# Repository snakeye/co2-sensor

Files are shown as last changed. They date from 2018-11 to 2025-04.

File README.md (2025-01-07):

# Carbon Dioxide Sensor MH-Z19b - ESP8266 Prototype

This project utilizes the MH-Z19b carbon dioxide sensor module, which provides a simple and cost-effective way to measure CO2 concentration via UART interface. The sensor measures concentrations in the range of 0-5000ppm, making it suitable for various environmental monitoring applications.

The device is built using the ESP12e module and features an RGB LED to indicate CO2 concentration levels.

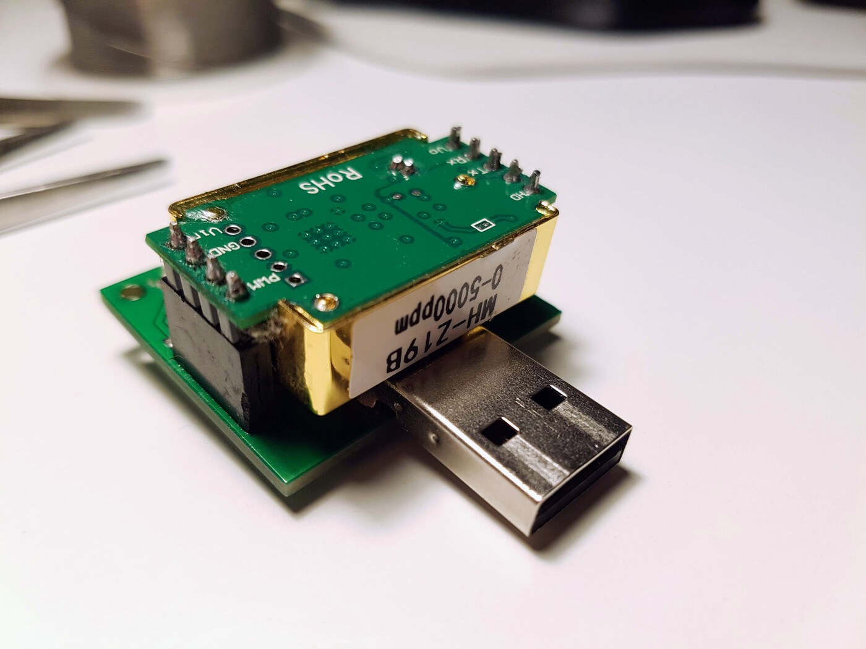
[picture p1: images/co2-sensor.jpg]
CO2 Sensor


## Features

- **CO2 concentration measurement** from 400ppm to 5000ppm using the MH-Z19b sensor.
- **RGB LED indication** with different light modes based on CO2 levels.
  
### LED Modes:

- **Steady Green Light**: CO2 concentration in the range of 400-1000ppm (normal levels).
- **Breathing Light**: Color changes from green to orange as CO2 levels increase from 1000 to 1500ppm.
- **Fast Breathing Light**: Color changes from orange to red as CO2 levels increase from 1500 to 2000ppm.
- **Fast Blinking Red Light**: CO2 concentration exceeds 2000ppm (dangerous levels).
- **Steady Blue Light**: Indicates that an OTA (Over-the-Air) update is in progress.

## Firmware

The firmware for the device is written using **PlatformIO** and the **Arduino** platform. The software controls the sensor, processes the data, and adjusts the LED indications based on the CO2 concentration.

## License

This project is licensed under the MIT License - see the [LICENSE](LICENSE) file for details.

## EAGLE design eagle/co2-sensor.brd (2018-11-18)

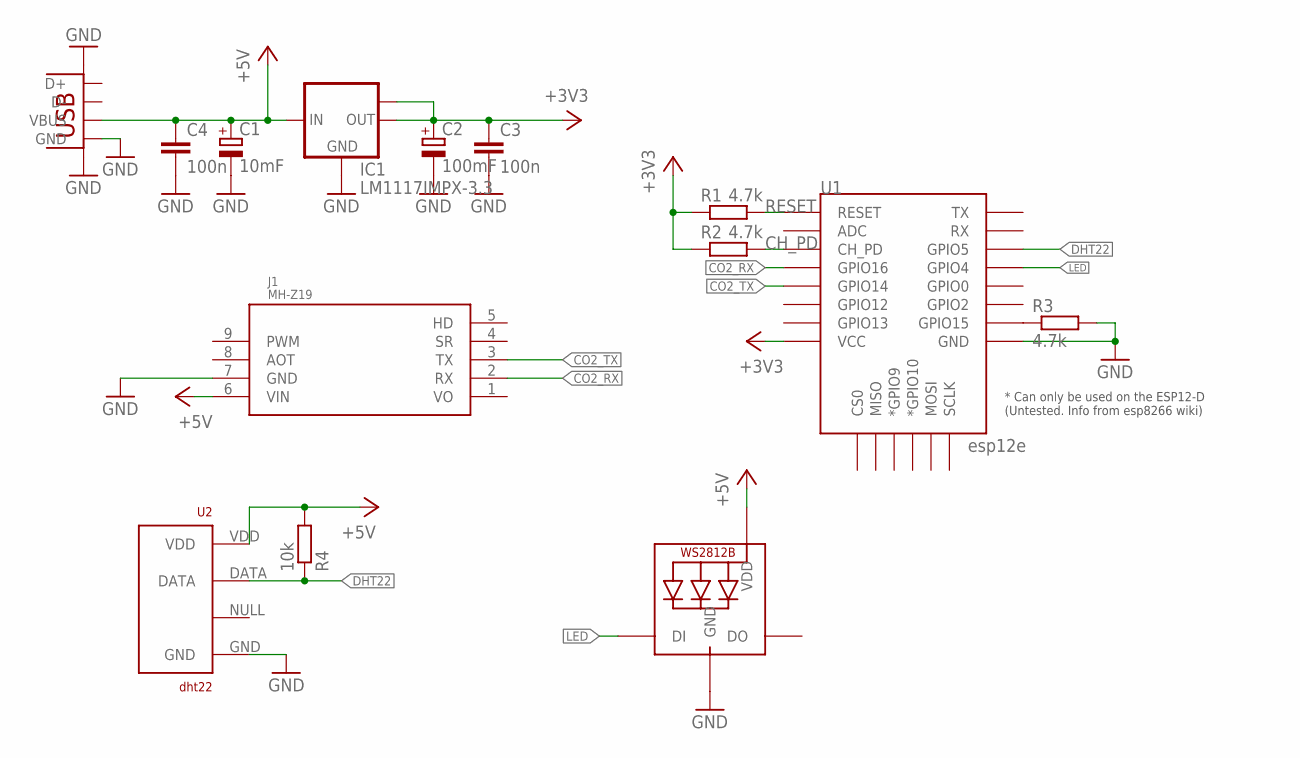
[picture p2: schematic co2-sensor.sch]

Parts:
C1: 10mF; CT3216
C2: 100mF; CT3216
C3, C4: 100n; C0805
IC1: LM1117IMPX-3.3; SOT223
J1: MH-Z19; MH-Z19-REV
LED1: WS2812B_5050N; WS2812B-NARROW
R1, R2, R3: 4.7k; M0805
R4: 10k; M0805
U1: esp12e; ESP12E-SMD
U2: dht22; AM2302
U$1: USB-A; USB-A-SMT

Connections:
+3V3: C2.+, C3.1, IC1.2 (OUT), IC1.TAB (OUT1), R1.1, R2.1, U1.VCC
+5V: C1.+, C4.1, IC1.3 (IN), J1.6 (VIN), LED1.1-VDD (VDD), R4.2, U2.VDD, U$1.P$6 (VBUS)
CH_PD: R2.2, U1.CH_PD
CO2_RX: J1.2 (RX), U1.GPIO16
CO2_TX: J1.3 (TX), U1.GPIO14
DHT22: R4.1, U1.GPIO5, U2.DATA
GND: C1.-, C2.-, C3.2, C4.2, IC1.1 (GND), J1.7 (GND), LED1.3-GND (GND), R3.2, U1.GND, U2.GND, U$1.P$1 (GND), U$1.P$2 (GND), U$1.P$3 (GND)
LED: LED1.4-DIN (DI), U1.GPIO4
unnamed: R3.1, U1.GPIO15
RESET: R1.2, U1.RESET
VO: J1.1 (VO)

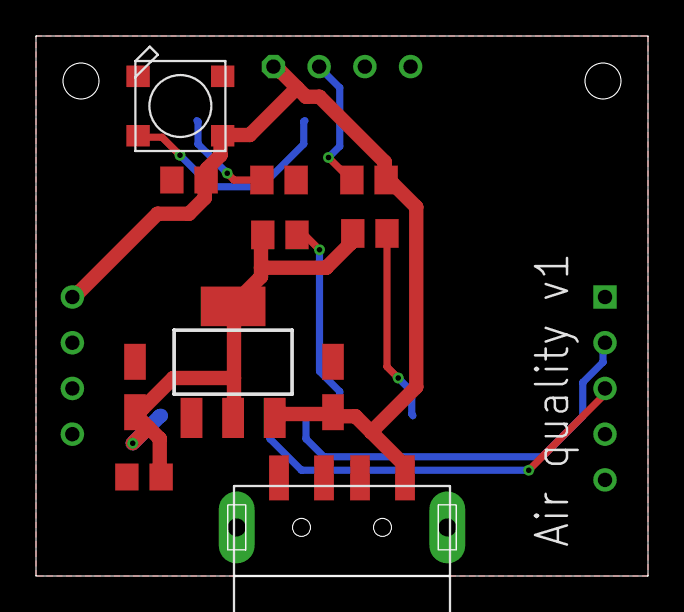
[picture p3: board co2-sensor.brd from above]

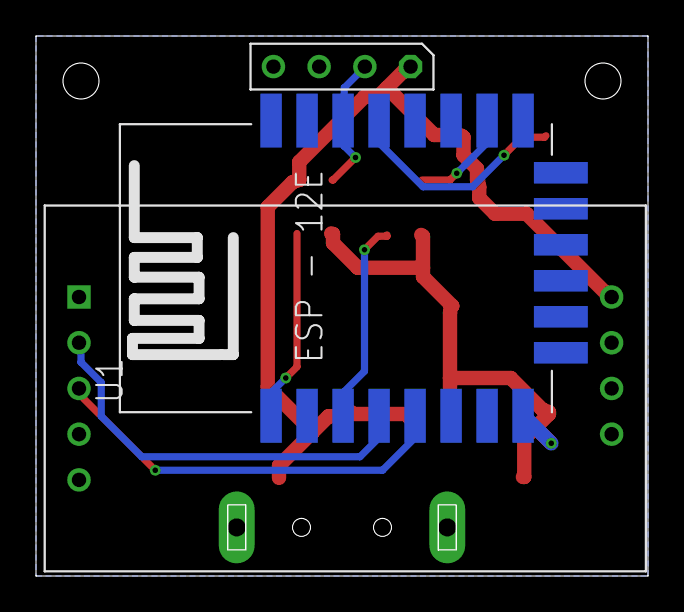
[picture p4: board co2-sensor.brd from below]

Board: 2 copper layers, 34.0 x 30.0 mm, 14 parts (2 on the bottom side), 10 nets.

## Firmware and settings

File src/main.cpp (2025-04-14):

#define DHCPS_DEBUG

#include <Arduino.h>
#include <ESP8266mDNS.h>
#include <ArduinoOTA.h>
#include <PubSubClient.h>
#include <MHZ.h>
#include <WS2812FX.h>
#include <RecurringTask.h>
#include <ArduinoJson.h>

#include "config.h"
#include "util.h"

// === Constants ===
constexpr uint8_t PIN_MHZ_RX = 14;
constexpr uint8_t PIN_MHZ_TX = 16;

constexpr uint8_t PIN_LED = 15;
constexpr uint8_t LED_COUNT = 1;

constexpr int SPEED_SLOW = 5000;
constexpr int SPEED_FAST = 1000;

constexpr int LEVEL_GOOD = 1000;
constexpr int LEVEL_WARNING = 1500;
constexpr int LEVEL_DANGER = 2000;

// === Globals ===
MHZ co2(PIN_MHZ_RX, PIN_MHZ_TX, MHZ::MHZ19B);
bool isCalibrated = false;

WS2812FX ws2812fx(LED_COUNT, PIN_LED, NEO_GRB + NEO_KHZ800);

WiFiClient espClient;
PubSubClient mqttClient(espClient);

String deviceId = String("co2mon_") + ESP.getChipId();

// === LED Utils ===
inline void setBrightness(uint8_t brightness)
{
    static uint8_t prev = 0;
    setIfChanged(prev, brightness, [](uint8_t b)
                 { ws2812fx.setBrightness(b); });
}

inline void setColor(uint32_t color)
{
    static uint32_t prev = 0;
    setIfChanged(prev, color, [](uint32_t c)
                 { ws2812fx.setColor(c); });
}

inline void setSpeed(uint16_t speed)
{
    static uint16_t prev = 0;
    setIfChanged(prev, speed, [](uint16_t s)
                 { ws2812fx.setSpeed(s); });
}

inline void setMode(uint8_t mode)
{
    static uint8_t prev = 0;
    setIfChanged(prev, mode, [](uint8_t m)
                 { ws2812fx.setMode(m); });
}

// === OTA ===
void setupOTA()
{
    ArduinoOTA.setHostname(hostName);
    ArduinoOTA.onStart([]()
                       {
        ws2812fx.setBrightness(5);
        ws2812fx.setColor(rgb(0, 0, 255));
        ws2812fx.setMode(FX_MODE_STATIC);
        ws2812fx.service(); });
    ArduinoOTA.onEnd([]()
                     {
        ws2812fx.setBrightness(25);
        ws2812fx.setColor(rgb(0, 0, 255));
        ws2812fx.setMode(FX_MODE_STATIC);
        ws2812fx.service(); });
    ArduinoOTA.begin();
}

// === WiFi ===
void connectWiFi()
{
    WiFi.mode(WIFI_STA);
    WiFi.setHostname(hostName);
    WiFi.begin(ssid, password);

    while (WiFi.status() != WL_CONNECTED)
    {
        delay(10);
        ws2812fx.service();
    }
    Serial.println("WiFi connected");
}

// === MQTT ===
std::vector<String> buildDiscoveryPayloads()
{
    std::vector<String> payloads;

    String chipId = String(ESP.getChipId());
    String baseTopic = "sensors/mhz19b-" + chipId;

    // === CO2 Sensor ===
    {
        StaticJsonDocument<512> doc;
        doc["name"] = "CO2";
        doc["state_topic"] = baseTopic + "/co2";
        doc["unit_of_measurement"] = "ppm";
        doc["device_class"] = "carbon_dioxide";
        doc["state_class"] = "measurement";
        doc["expire_after"] = 120;
        doc["unique_id"] = "co2-" + chipId;

        JsonObject device = doc.createNestedObject("device");
        device["identifiers"][0] = deviceId;
        device["name"] = deviceName;
        device["manufacturer"] = "DIY";
        device["model"] = "MH-Z19B CO2 Sensor";
        device["sw_version"] = "1.0";

        String output;
        serializeJson(doc, output);
        payloads.push_back(output);
    }

    // === Temperature Sensor ===
    {
        StaticJsonDocument<512> doc;
        doc["name"] = "Temperature";
        doc["state_topic"] = baseTopic + "/temperature";
        doc["unit_of_measurement"] = "°C";
        doc["device_class"] = "temperature";
        doc["state_class"] = "measurement";
        doc["expire_after"] = 120;
        doc["unique_id"] = "temp-" + chipId;

        JsonObject device = doc.createNestedObject("device");
        device["identifiers"][0] = deviceId;
        device["name"] = deviceName;
        device["manufacturer"] = "DIY";
        device["model"] = "MH-Z19B CO2 Sensor";
        device["sw_version"] = "1.0";

        String output;
        serializeJson(doc, output);
        payloads.push_back(output);
    }

    // // === Calibration Status (binary sensor) ===
    // {
    //     StaticJsonDocument<512> doc;
    //     doc["name"] = "Calibrated";
    //     doc["state_topic"] = baseTopic + "/calibrated";
    //     doc["device_class"] = "running"; // можно "running" или "problem"
    //     doc["expire_after"] = 120;
    //     doc["unique_id"] = "calibrated-" + chipId;
    //     doc["payload_on"] = "true";
    //     doc["payload_off"] = "false";

    //     doc["device"]["identifiers"][0] = deviceId;
    //     doc["device"]["name"] = deviceName;
    //     doc["device"]["manufacturer"] = "DIY";
    //     doc["device"]["model"] = "MH-Z19B CO2 Sensor";
    //     doc["device"]["sw_version"] = "1.0";

    //     String output;
    //     serializeJson(doc, output);
    //     payloads.push_back(output);
    // }

    return payloads;
}

void publishDiscoveryPayloads()
{
    auto payloads = buildDiscoveryPayloads();

    String chipId = String(ESP.getChipId());

    mqttClient.publish(
        ("homeassistant/sensor/mhz19b-" + chipId + "-co2/config").c_str(),
        payloads[0].c_str(), true);

    mqttClient.publish(
        ("homeassistant/sensor/mhz19b-" + chipId + "-temp/config").c_str(),
        payloads[1].c_str(), true);

    // mqttClient.publish(
    //     ("homeassistant/binary_sensor/mhz19b-" + chipId + "-calibrated/config").c_str(),
    //     payloads[2].c_str(), true);
}

void reconnectMQTT()
{
    while (!mqttClient.connected())
    {
        Serial.print("Attempting MQTT connection...");

        if (mqttClient.connect("MHZ19B_Client"))
        {
            Serial.println("connected");
            publishDiscoveryPayloads();
        }
        else
        {
            Serial.printf("failed, rc=%d. Retrying in 5s...\n", mqttClient.state());
            delay(5000);
        }
    }
}

void publishCO2Data(int ppm)
{
    String chipId = String(ESP.getChipId());
    mqttClient.publish(String("sensors/mhz19b-" + chipId + "/co2").c_str(), String(ppm).c_str(), true);
}

void publishTemperatureData(float temperature)
{
    String chipId = String(ESP.getChipId());
    mqttClient.publish(String("sensors/mhz19b-" + chipId + "/temperature").c_str(), String(temperature).c_str(), true);
}

void publishCalibrated()
{
    String chipId = String(ESP.getChipId());
    mqttClient.publish(String("sensors/mhz19b-" + chipId + "/calibrated").c_str(), isCalibrated ? "true" : "false", true);
}

// === CO2 Reading ===
void updateLedEffect(int ppm)
{
    if (ppm <= LEVEL_GOOD)
    {
        setBrightness(5);
        setColor(rgb(0, 255, 0));
        setMode(FX_MODE_STATIC);
        setSpeed(SPEED_SLOW);
    }
    else if (ppm <= LEVEL_WARNING)
    {
        setBrightness(5);

        uint32_t r = transform(ppm, range(LEVEL_GOOD, LEVEL_WARNING), range(0, 255));
        setColor(rgb(r, 255, 0));

        uint16_t speed = transform(ppm, range(LEVEL_GOOD, LEVEL_DANGER), range(SPEED_FAST, SPEED_SLOW));
        setSpeed(speed);
        setMode(FX_MODE_BREATH);
    }
    else if (ppm <= LEVEL_DANGER)
    {
        uint8_t brightness = transform(ppm, range(LEVEL_WARNING, LEVEL_DANGER), range(5, 20));
        uint32_t g = transform(ppm, range(LEVEL_WARNING, LEVEL_DANGER), range(0, 255));
        uint16_t speed = transform(ppm, range(LEVEL_GOOD, LEVEL_DANGER), range(SPEED_FAST, SPEED_SLOW));

        setBrightness(brightness);
        setColor(rgb(255, g, 0));
        setSpeed(speed);
        setMode(FX_MODE_BREATH);
    }
    else
    {
        setBrightness(20);
        setColor(rgb(255, 0, 0));
        setSpeed(SPEED_FAST);
        setMode(FX_MODE_STROBE);
    }
}

void measureCO2()
{
    if (co2.isPreHeating())
    {
        setBrightness(5);
        setColor(rgb(0, 192, 255));
        setMode(FX_MODE_STATIC);
        return;
    }

    digitalWrite(LED_BUILTIN, LOW);
    int ppm = co2.readCO2UART();
    float temperature = co2.getLastTemperature();
    digitalWrite(LED_BUILTIN, HIGH);

    Serial.print("PPMuart: ");
    Serial.println(ppm > 0 ? String(ppm) : "n/a");

    if (ppm > 0)
    {
        updateLedEffect(ppm);
        publishCO2Data(ppm);
        publishTemperatureData(temperature);
    }
}

// === Optional: Calibration ===
void calibrateSensor()
{
    const unsigned long waitMs = TIME_TO_MS(0, 30, 0);
    if (!isCalibrated && millis() > waitMs)
    {
        co2.calibrateZero();
        isCalibrated = true;

        publishCalibrated();
    }
}

// === Setup ===
void setup()
{
    Serial.begin(115200);
    pinMode(LED_BUILTIN, OUTPUT);
    digitalWrite(LED_BUILTIN, HIGH);

    co2.setAutoCalibrate(false);
    co2.setBypassCheck(true, true);
    co2.setDebug(false);

    ws2812fx.init();
    ws2812fx.start();

    setBrightness(15);
    setColor(rgb(255, 255, 255));
    setMode(FX_MODE_BREATH);
    setSpeed(SPEED_FAST);

    connectWiFi();
    setBrightness(5);
    setColor(rgb(0, 0, 255));
    setMode(FX_MODE_BREATH);
    setSpeed(SPEED_SLOW);

    MDNS.begin(deviceName);
    setupOTA();

    mqttClient.setServer(mqttServer, mqttPort);
}

// === Main loop ===
void loop()
{
    if (!mqttClient.connected())
    {
        reconnectMQTT();
        publishCalibrated();
    }

    mqttClient.loop();
    ws2812fx.service();
    ArduinoOTA.handle();

    RecurringTask::interval(10000, []()
                            { measureCO2(); });

    // RecurringTask::interval(1000, []()
    //                         { calibrateSensor(); });

    delay(1);
}

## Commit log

2018-10-22 Eagle schematic and board
    [co2-sensor.brd, co2-sensor.sch]
2018-11-17 fixed prototype issues
    [co2-sensor.brd, co2-sensor.sch]
2025-04-10 refactor, home assistant, arduino json
